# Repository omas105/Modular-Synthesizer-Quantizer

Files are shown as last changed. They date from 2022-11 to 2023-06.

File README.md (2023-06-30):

# Modular-Synthesizer-Quantizer
Modular Synthesizer Quantizer with Arduino nano and MCP4921 DAC

Inspired by [Hagiwo](https://note.com/solder_state/n/nde97a0516f03) and [luislutz's](https://github.com/luislutz/Arduino_Quantizer) design

<table>
  <tr>    
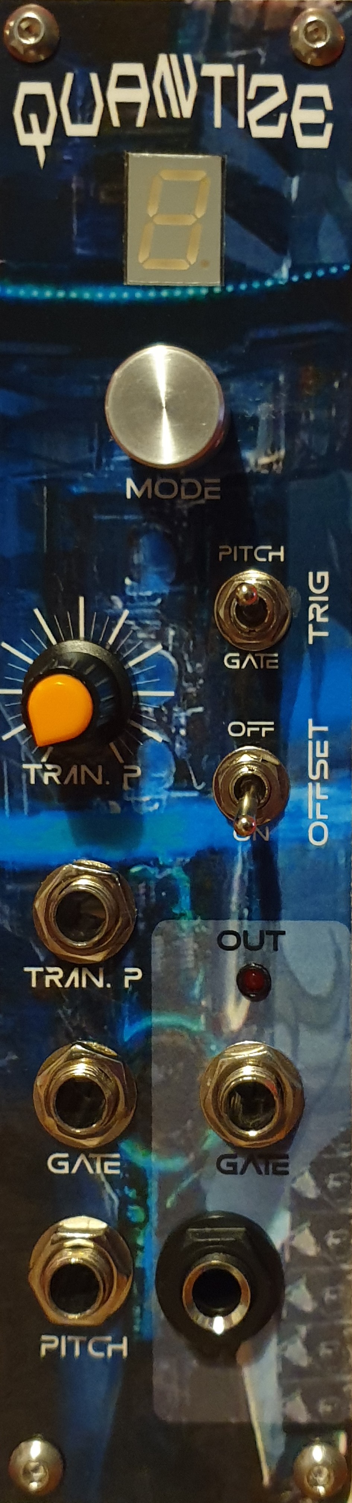
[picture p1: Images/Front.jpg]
    <td></td>
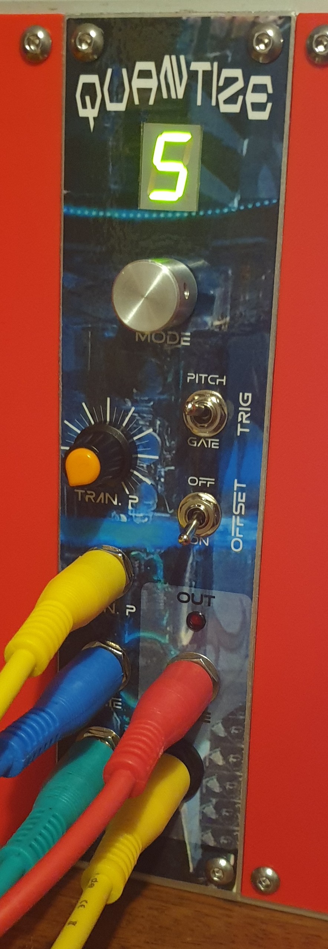
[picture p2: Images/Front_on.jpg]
    <td></td>
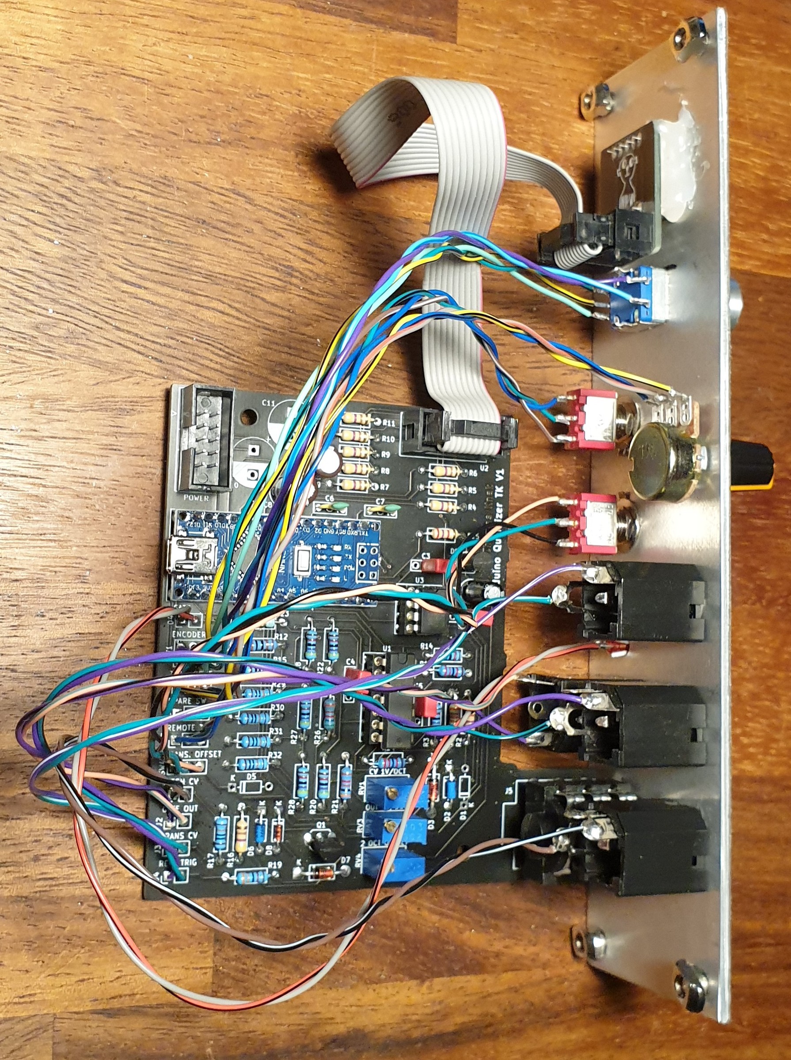
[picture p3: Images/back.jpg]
    <td></td>
  </tr>
 </table>

## Inputs
Pitch CV [0-7V] - Voltage to be quantized.

Trigger [2-12V] - Generate new quantized CV.

Transpose [0-5V] - Transpose quantized CV.

## Outputs
QV [0-9V] - Quantized CV.

Gate [0-10V] - Generates a pulse when QV i changed.

## Knops and switches
Transpose knop - Transpose QV 7 octaves.

Trigger switch - In OFF state QV is only changes when reciving a input trigger signal. In ON state QV is changes when pitch CV or transpose changes to a new note.

Offset switch - Transpose QV 2 octaves.

Mode selector - Encoder to change scales, transpose mode and root note.

<table>
  <tr>
   <td><b>Scale</b></td>
   <td><b>Root note</b></td>
   <td><b>Transpose mode</b></td>   
 </tr>
  <td>Turn mode knop</td>
  <td>Click and hold mode knop while turning</td>
  <td>Double click and turn mode knop</td>
 <tr>    
   <td>
    
| Number | Scale |
|---|---|
|0 |Major|
|1 |Major pentatonic|
|2 |Major pentatonic + 7|
|3 |Natural Minor|
|4 |Minor pentatonic|
|5 |Harmonic minor|
|6 |Melodic minor|
|7 |Blues|
|8 |Chromatic|
|9 |Octave|
   </td>

   <td>
    
| Display | Note |
|---|---|
| C | C |
| C. | C# |
| d | D |
| d. | D# |
| E | E |
| F | F |
| F. | F# |
| G | G |
| G. | G# |
| A | A |
| A. | A# |
| b | B |
   </td>

   <td>
     
| Display | Mode |
|-|-|
| Top | 12 Semitones
| Midt | 7 Semitones|
| Bottom | 1 Semitone| 
   </td>
  
  </tr>
 </table>

# PCB

<table>
  <tr>
    <td>Front</td>
    <td>Back</td>
  </tr>
  <tr>    
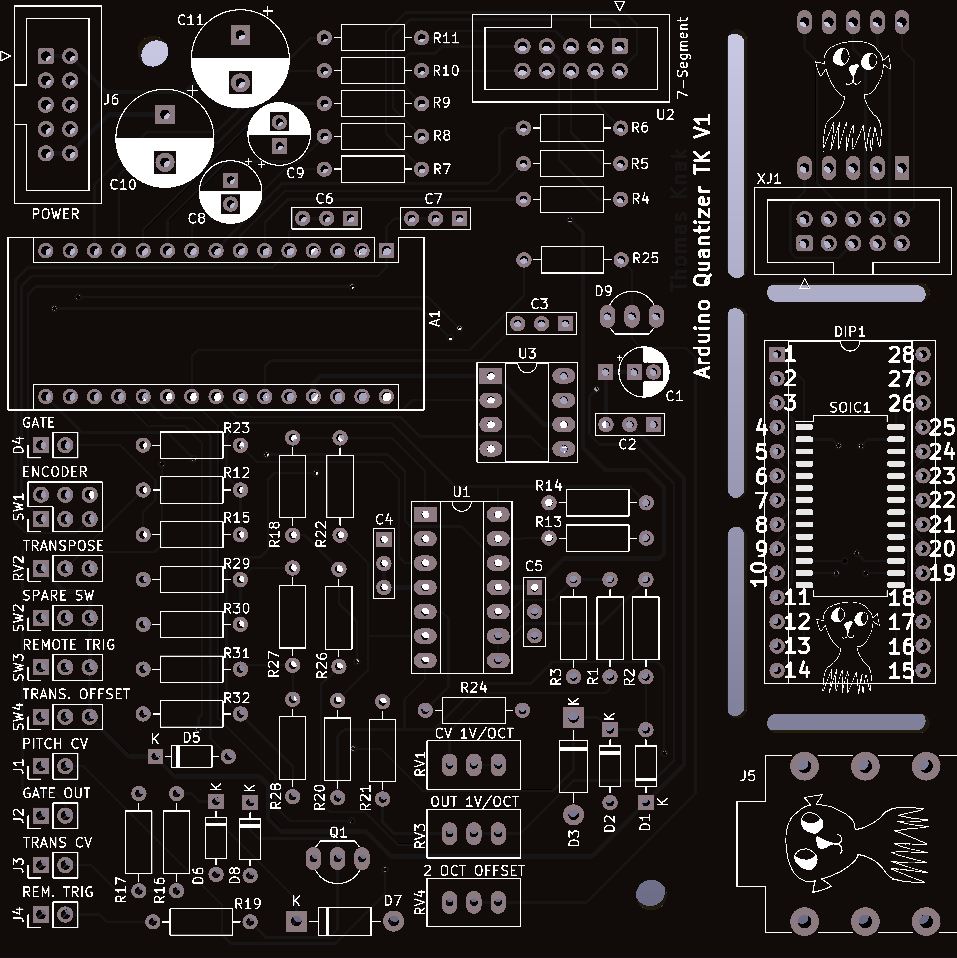
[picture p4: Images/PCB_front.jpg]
    <td></td>
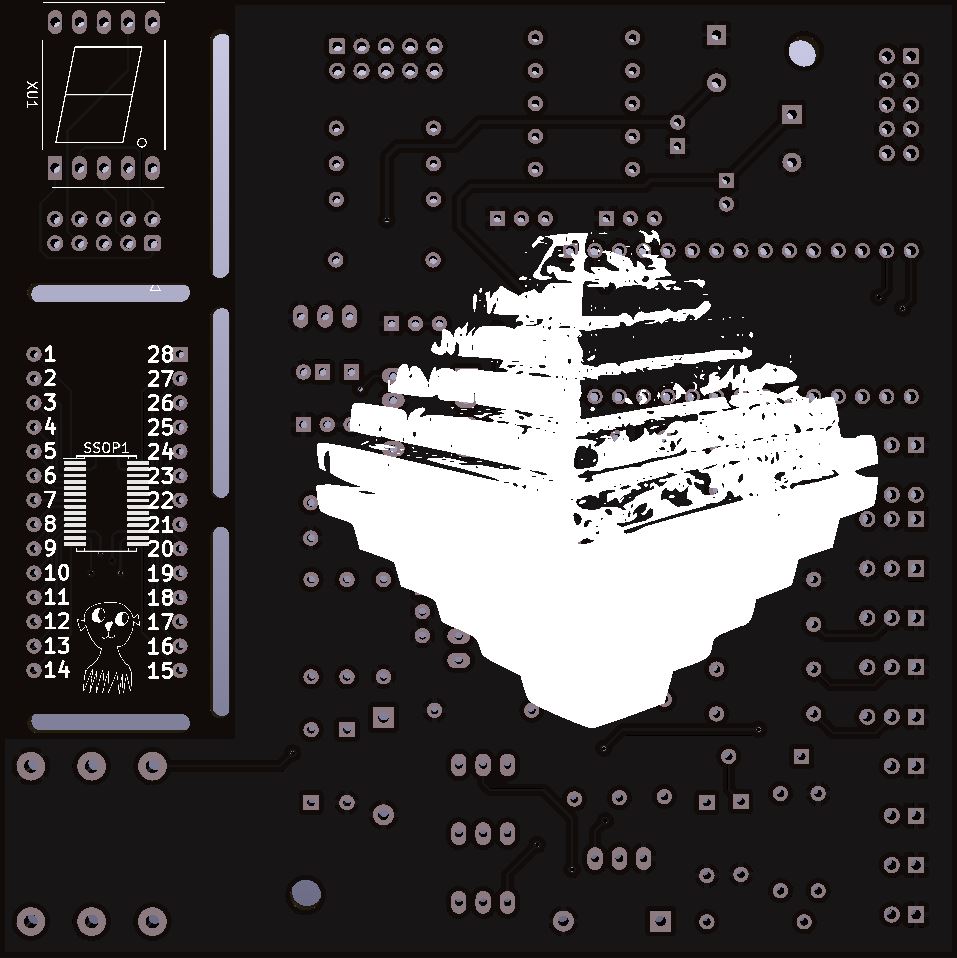
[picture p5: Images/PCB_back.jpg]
    <td></td>
  </tr>
 </table>

## License

[GNU General Public License (GPLv3)](LICENSE)

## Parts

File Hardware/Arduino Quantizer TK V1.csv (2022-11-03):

Source: | C:\Users\Thomas\Documents\Modular Synthesizer\TK Projektor\Arduino Quantizer TK\Hardware\Arduino Quantizer TK V1.sch
Date: | 03-11-2022 17:30:33
Tool: | Eeschema (5.1.10)-1
Generator: | C:\Program Files\KiCad\bin\scripting\plugins/bom_csv_grouped_by_value.py
Component Count: | 77
Individual Components:
Item | Qty | Reference(s) | Value | LibPart | Footprint | Datasheet | Text | text
 |  | A1 | Arduino_Nano_v3.x | MCU_Module:Arduino_Nano_v3.x | Module:Arduino_Nano | http://www.mouser.com/pdfdocs/Gravitech_Arduino_Nano3_0.pdf
 |  | C1 | 4µ7 | Device:CP | Thomas PCB:CP_Radial_D5.0mm_P2.00mm_P5.00mm | ~
 |  | C2 | 100n | Device:C | Thomas PCB:C_Rect_L7.0mm_W2.0mm_P2.50_P5.00mm | ~
 |  | C3 | 100n | Device:C | Thomas PCB:C_Rect_L7.0mm_W2.0mm_P2.50_P5.00mm | ~
 |  | C4 | 100n | Device:C | Thomas PCB:C_Rect_L7.0mm_W2.0mm_P2.50_P5.00mm | ~
 |  | C5 | 100n | Device:C | Thomas PCB:C_Rect_L7.0mm_W2.0mm_P2.50_P5.00mm | ~
 |  | C6 | 10n | Device:C | Thomas PCB:C_Rect_L7.0mm_W2.0mm_P2.50_P5.00mm | ~
 |  | C7 | 10n | Device:C | Thomas PCB:C_Rect_L7.0mm_W2.0mm_P2.50_P5.00mm | ~
 |  | C8 | 47µ | Device:CP | Capacitor_THT:CP_Radial_D6.3mm_P2.50mm | ~
 |  | C9 | 47µ | Device:CP | Capacitor_THT:CP_Radial_D6.3mm_P2.50mm | ~
 |  | C10 | 220µ | Device:CP | Thomas PCB:CP_Radial_D10.0mm_P5.00mm | ~
 |  | C11 | 220µ | Device:CP | Thomas PCB:CP_Radial_D10.0mm_P5.00mm | ~
 |  | D1 | BAT43 | Diode:BAT43 | Diode_THT:D_DO-35_SOD27_P7.62mm_Horizontal | http://www.vishay.com/docs/85660/bat42.pdf
 |  | D2 | BAT43 | Diode:BAT43 | Diode_THT:D_DO-35_SOD27_P7.62mm_Horizontal | http://www.vishay.com/docs/85660/bat42.pdf
 |  | D3 | 1N4733 5.1V | Diode:1N47xxA | Diode_THT:D_DO-41_SOD81_P10.16mm_Horizontal | https://www.vishay.com/docs/85816/1n4728a.pdf |  | 5.1V
 |  | D4 | Gate out LED | Device:LED_ALT | Connector_PinHeader_2.54mm:PinHeader_1x02_P2.54mm_Vertical | ~
 |  | D5 | BAT43 | Diode:BAT43 | Diode_THT:D_DO-35_SOD27_P7.62mm_Horizontal | http://www.vishay.com/docs/85660/bat42.pdf
 |  | D6 | BAT43 | Diode:BAT43 | Diode_THT:D_DO-35_SOD27_P7.62mm_Horizontal | http://www.vishay.com/docs/85660/bat42.pdf
 |  | D7 | 1N4733 5.1V | Diode:1N47xxA | Diode_THT:D_DO-41_SOD81_P10.16mm_Horizontal | https://www.vishay.com/docs/85816/1n4728a.pdf |  | 5.1V
 |  | D8 | 1N4148 | Diode:1N4148 | Diode_THT:D_DO-35_SOD27_P7.62mm_Horizontal | https://assets.nexperia.com/documents/data-sheet/1N4148_1N4448.pdf
 |  | D9 | LM336-2.5V | Thomas_Symbols:LM336-2.5V | Thomas PCB:TO-92_Inline_Wide_Longpads | ~
 |  | DIP1 | Conn_01x28 | Connector_Generic:Conn_01x28 | Package_DIP:DIP-28_W15.24mm_Socket | ~
 |  | J1 | Pitch CV | Connector:AudioJack2_SwitchT | Thomas PCB:Jack_PinHeader_1x02_P2.54mm_Vertical | ~ | 0-7V
 |  | J2 | Gate out | Connector:AudioJack2 | Thomas PCB:Jack_PinHeader_1x02_P2.54mm_Vertical | ~ |  | 0-10V
 |  | J3 | Transpose CV | Connector:AudioJack2_SwitchT | Thomas PCB:Jack_PinHeader_1x02_P2.54mm_Vertical | ~ | 0-5V
 |  | J4 | Remote trigger | Connector:AudioJack2 | Thomas PCB:Jack_PinHeader_1x02_P2.54mm_Vertical | ~ | 2-12V
 |  | J5 | QV out | Connector:AudioJack2 | Connector_Audio:Jack_6.35mm_Neutrik_NMJ6HFD2_Horizontal | ~
 |  | J6 | Power | Thomas_Symbols:Eurorack_power_Conn_01x10 | Connector_IDC:IDC-Header_2x05_P2.54mm_Vertical | ~
 |  | Q1 | BC547 | Transistor_BJT:BC547 | Thomas PCB:TO-92_Inline_Wide_Longpads | https://www.onsemi.com/pub/Collateral/BC550-D.pdf
 |  | R1 | 16K | Device:R | Resistor_THT:R_Axial_DIN0207_L6.3mm_D2.5mm_P10.16mm_Horizontal | ~
 |  | R2 | 470R | Device:R | Resistor_THT:R_Axial_DIN0207_L6.3mm_D2.5mm_P10.16mm_Horizontal | ~
 |  | R3 | 47K | Device:R | Resistor_THT:R_Axial_DIN0207_L6.3mm_D2.5mm_P10.16mm_Horizontal | ~
 |  | R4 | 300E | Device:R | Resistor_THT:R_Axial_DIN0207_L6.3mm_D2.5mm_P10.16mm_Horizontal | ~
 |  | R5 | 300E | Device:R | Resistor_THT:R_Axial_DIN0207_L6.3mm_D2.5mm_P10.16mm_Horizontal | ~
 |  | R6 | 300E | Device:R | Resistor_THT:R_Axial_DIN0207_L6.3mm_D2.5mm_P10.16mm_Horizontal | ~
 |  | R7 | 300E | Device:R | Resistor_THT:R_Axial_DIN0207_L6.3mm_D2.5mm_P10.16mm_Horizontal | ~
 |  | R8 | 300E | Device:R | Resistor_THT:R_Axial_DIN0207_L6.3mm_D2.5mm_P10.16mm_Horizontal | ~
 |  | R9 | 300E | Device:R | Resistor_THT:R_Axial_DIN0207_L6.3mm_D2.5mm_P10.16mm_Horizontal | ~
 |  | R10 | 300E | Device:R | Resistor_THT:R_Axial_DIN0207_L6.3mm_D2.5mm_P10.16mm_Horizontal | ~
 |  | R11 | 300E | Device:R | Resistor_THT:R_Axial_DIN0207_L6.3mm_D2.5mm_P10.16mm_Horizontal | ~
 |  | R12 | 1K | Device:R | Resistor_THT:R_Axial_DIN0207_L6.3mm_D2.5mm_P10.16mm_Horizontal | ~
 |  | R13 | 24K | Device:R | Resistor_THT:R_Axial_DIN0207_L6.3mm_D2.5mm_P10.16mm_Horizontal | ~
 |  | R14 | 47K | Device:R | Resistor_THT:R_Axial_DIN0207_L6.3mm_D2.5mm_P10.16mm_Horizontal | ~
 |  | R15 | 10K | Device:R | Resistor_THT:R_Axial_DIN0207_L6.3mm_D2.5mm_P10.16mm_Horizontal | ~
 |  | R16 | 470R | Device:R | Resistor_THT:R_Axial_DIN0207_L6.3mm_D2.5mm_P10.16mm_Horizontal | ~
 |  | R17 | 100K | Device:R | Resistor_THT:R_Axial_DIN0207_L6.3mm_D2.5mm_P10.16mm_Horizontal | ~
 |  | R18 | 47K | Device:R | Resistor_THT:R_Axial_DIN0207_L6.3mm_D2.5mm_P10.16mm_Horizontal | ~
 |  | R19 | 33K | Device:R | Resistor_THT:R_Axial_DIN0207_L6.3mm_D2.5mm_P10.16mm_Horizontal | ~
 |  | R20 | 47K | Device:R | Resistor_THT:R_Axial_DIN0207_L6.3mm_D2.5mm_P10.16mm_Horizontal | ~
 |  | R21 | 30K | Device:R | Resistor_THT:R_Axial_DIN0207_L6.3mm_D2.5mm_P10.16mm_Horizontal | ~
 |  | R22 | 47K | Device:R | Resistor_THT:R_Axial_DIN0207_L6.3mm_D2.5mm_P10.16mm_Horizontal | ~
 |  | R23 | 22K | Device:R | Resistor_THT:R_Axial_DIN0207_L6.3mm_D2.5mm_P10.16mm_Horizontal | ~
 |  | R24 | 22K | Device:R | Resistor_THT:R_Axial_DIN0207_L6.3mm_D2.5mm_P10.16mm_Horizontal | ~
 |  | R25 | 2K7 | Device:R | Resistor_THT:R_Axial_DIN0207_L6.3mm_D2.5mm_P10.16mm_Horizontal | ~
 |  | R26 | 56K | Device:R | Resistor_THT:R_Axial_DIN0207_L6.3mm_D2.5mm_P10.16mm_Horizontal | ~
 |  | R27 | 47K | Device:R | Resistor_THT:R_Axial_DIN0207_L6.3mm_D2.5mm_P10.16mm_Horizontal | ~
 |  | R28 | 47K | Device:R | Resistor_THT:R_Axial_DIN0207_L6.3mm_D2.5mm_P10.16mm_Horizontal | ~
 |  | R29 | 100K | Device:R | Resistor_THT:R_Axial_DIN0207_L6.3mm_D2.5mm_P10.16mm_Horizontal | ~
 |  | R30 | 100K | Device:R | Resistor_THT:R_Axial_DIN0207_L6.3mm_D2.5mm_P10.16mm_Horizontal | ~
 |  | R31 | 100K | Device:R | Resistor_THT:R_Axial_DIN0207_L6.3mm_D2.5mm_P10.16mm_Horizontal | ~
 |  | R32 | 100K | Device:R | Resistor_THT:R_Axial_DIN0207_L6.3mm_D2.5mm_P10.16mm_Horizontal | ~
 |  | RV1 | 5K | Device:R_POT | Thomas PCB:Potentiometer_Bourns_3296W_Vertical_longpads_2 | ~
 |  | RV2 | 100K | Device:R_POT | Connector_PinHeader_2.54mm:PinHeader_1x03_P2.54mm_Vertical | ~ | Transpose
 |  | RV3 | 10K | Device:R_POT | Thomas PCB:Potentiometer_Bourns_3296W_Vertical_longpads_2 | ~
 |  | RV4 | 5K | Device:R_POT | Thomas PCB:Potentiometer_Bourns_3296W_Vertical_longpads_2 | ~
 |  | SOIC1 | Conn_01x28 | Connector_Generic:Conn_01x28 | Package_SO:SOIC-28W_7.5x18.7mm_P1.27mm | ~
 |  | SSOP1 | Conn_01x28 | Connector_Generic:Conn_01x28 | Package_SO:TSSOP-28_6.1x9.7mm_P0.65mm | ~
 |  | SSOP2 | Conn_01x28 | Connector_Generic:Conn_01x28 | Package_SO:TSSOP-28_4.4x9.7mm_P0.65mm | ~
 |  | SW1 | Rotary_Encoder_Switch | Device:Rotary_Encoder_Switch | Thomas PCB:Encoder_with_Switch_PinHeader_2x03_P2.54mm_Vertical | ~
 |  | SW2 | Spare SW | Switch:SW_SPDT | Connector_PinHeader_2.54mm:PinHeader_1x03_P2.54mm_Vertical | ~
 |  | SW3 | Remote trig | Switch:SW_SPDT | Connector_PinHeader_2.54mm:PinHeader_1x03_P2.54mm_Vertical | ~
 |  | SW4 | Transpose Offset | Switch:SW_SPDT | Connector_PinHeader_2.54mm:PinHeader_1x03_P2.54mm_Vertical | ~
 |  | U1 | TL074 | Amplifier_Operational:TL074 | Package_DIP:DIP-14_W7.62mm_Socket_LongPads | http://www.ti.com/lit/ds/symlink/tl071.pdf
 |  | U2 | SC52-11GWA | Display_Character:KCSC02-123 | Thomas PCB:Eurorack_power_IDC-Header_2x05_P2.54mm_Vertical | http://www.kingbright.com/attachments/file/psearch/000/00/00/KCSC02-123(Ver.10A).pdf
 |  | U3 | MCP4921-EP | Analog_DAC:MCP4921-EP | Package_DIP:DIP-8_W7.62mm_Socket_LongPads | http://ww1.microchip.com/downloads/en/devicedoc/21897a.pdf
 |  | XJ1 | 7-Segment | Thomas_Symbols:Eurorack_power_Conn_01x10 | Connector_IDC:IDC-Header_2x05_P2.54mm_Vertical | ~
 |  | XU1 | SC52-11GWA | Display_Character:KCSC02-123 | Thomas PCB:7Segment_SC52-11GWA | http://www.kingbright.com/attachments/file/psearch/000/00/00/KCSC02-123(Ver.10A).pdf
Collated Components:
Item | Qty | Reference(s) | Value | LibPart | Footprint | Datasheet | Text | text
1 | 1 | A1 | Arduino_Nano_v3.x | MCU_Module:Arduino_Nano_v3.x | Module:Arduino_Nano | http://www.mouser.com/pdfdocs/Gravitech_Arduino_Nano3_0.pdf
2 | 1 | C1 | 4µ7 | Device:CP | Thomas PCB:CP_Radial_D5.0mm_P2.00mm_P5.00mm | ~
3 | 4 | C2, C3, C4, C5 | 100n | Device:C | Thomas PCB:C_Rect_L7.0mm_W2.0mm_P2.50_P5.00mm | ~
4 | 2 | C6, C7 | 10n | Device:C | Thomas PCB:C_Rect_L7.0mm_W2.0mm_P2.50_P5.00mm | ~
5 | 2 | C8, C9 | 47µ | Device:CP | Capacitor_THT:CP_Radial_D6.3mm_P2.50mm | ~
6 | 2 | C10, C11 | 220µ | Device:CP | Thomas PCB:CP_Radial_D10.0mm_P5.00mm | ~
7 | 4 | D1, D2, D5, D6 | BAT43 | Diode:BAT43 | Diode_THT:D_DO-35_SOD27_P7.62mm_Horizontal | http://www.vishay.com/docs/85660/bat42.pdf
8 | 2 | D3, D7 | 1N4733 5.1V | Diode:1N47xxA | Diode_THT:D_DO-41_SOD81_P10.16mm_Horizontal | https://www.vishay.com/docs/85816/1n4728a.pdf |  | 5.1V
9 | 1 | D4 | Gate out LED | Device:LED_ALT | Connector_PinHeader_2.54mm:PinHeader_1x02_P2.54mm_Vertical | ~
10 | 1 | D8 | 1N4148 | Diode:1N4148 | Diode_THT:D_DO-35_SOD27_P7.62mm_Horizontal | https://assets.nexperia.com/documents/data-sheet/1N4148_1N4448.pdf
11 | 1 | D9 | LM336-2.5V | Thomas_Symbols:LM336-2.5V | Thomas PCB:TO-92_Inline_Wide_Longpads | ~
12 | 1 | DIP1 | Conn_01x28 | Connector_Generic:Conn_01x28 | Package_DIP:DIP-28_W15.24mm_Socket | ~
13 | 1 | J1 | Pitch CV | Connector:AudioJack2_SwitchT | Thomas PCB:Jack_PinHeader_1x02_P2.54mm_Vertical | ~ | 0-7V
14 | 1 | J2 | Gate out | Connector:AudioJack2 | Thomas PCB:Jack_PinHeader_1x02_P2.54mm_Vertical | ~ |  | 0-10V
15 | 1 | J3 | Transpose CV | Connector:AudioJack2_SwitchT | Thomas PCB:Jack_PinHeader_1x02_P2.54mm_Vertical | ~ | 0-5V
16 | 1 | J4 | Remote trigger | Connector:AudioJack2 | Thomas PCB:Jack_PinHeader_1x02_P2.54mm_Vertical | ~ | 2-12V
17 | 1 | J5 | QV out | Connector:AudioJack2 | Connector_Audio:Jack_6.35mm_Neutrik_NMJ6HFD2_Horizontal | ~
18 | 1 | J6 | Power | Thomas_Symbols:Eurorack_power_Conn_01x10 | Connector_IDC:IDC-Header_2x05_P2.54mm_Vertical | ~
19 | 1 | Q1 | BC547 | Transistor_BJT:BC547 | Thomas PCB:TO-92_Inline_Wide_Longpads | https://www.onsemi.com/pub/Collateral/BC550-D.pdf
20 | 1 | R1 | 16K | Device:R | Resistor_THT:R_Axial_DIN0207_L6.3mm_D2.5mm_P10.16mm_Horizontal | ~
21 | 2 | R2, R16 | 470R | Device:R | Resistor_THT:R_Axial_DIN0207_L6.3mm_D2.5mm_P10.16mm_Horizontal | ~
22 | 7 | R3, R14, R18, R20, R22, R27, R28 | 47K | Device:R | Resistor_THT:R_Axial_DIN0207_L6.3mm_D2.5mm_P10.16mm_Horizontal | ~
23 | 8 | R4, R5, R6, R7, R8, R9, R10, R11 | 300E | Device:R | Resistor_THT:R_Axial_DIN0207_L6.3mm_D2.5mm_P10.16mm_Horizontal | ~
24 | 1 | R12 | 1K | Device:R | Resistor_THT:R_Axial_DIN0207_L6.3mm_D2.5mm_P10.16mm_Horizontal | ~
25 | 1 | R13 | 24K | Device:R | Resistor_THT:R_Axial_DIN0207_L6.3mm_D2.5mm_P10.16mm_Horizontal | ~
26 | 1 | R15 | 10K | Device:R | Resistor_THT:R_Axial_DIN0207_L6.3mm_D2.5mm_P10.16mm_Horizontal | ~
27 | 5 | R17, R29, R30, R31, R32 | 100K | Device:R | Resistor_THT:R_Axial_DIN0207_L6.3mm_D2.5mm_P10.16mm_Horizontal | ~
28 | 1 | R19 | 33K | Device:R | Resistor_THT:R_Axial_DIN0207_L6.3mm_D2.5mm_P10.16mm_Horizontal | ~
29 | 1 | R21 | 30K | Device:R | Resistor_THT:R_Axial_DIN0207_L6.3mm_D2.5mm_P10.16mm_Horizontal | ~
30 | 2 | R23, R24 | 22K | Device:R | Resistor_THT:R_Axial_DIN0207_L6.3mm_D2.5mm_P10.16mm_Horizontal | ~
31 | 1 | R25 | 2K7 | Device:R | Resistor_THT:R_Axial_DIN0207_L6.3mm_D2.5mm_P10.16mm_Horizontal | ~
32 | 1 | R26 | 56K | Device:R | Resistor_THT:R_Axial_DIN0207_L6.3mm_D2.5mm_P10.16mm_Horizontal | ~
33 | 2 | RV1, RV4 | 5K | Device:R_POT | Thomas PCB:Potentiometer_Bourns_3296W_Vertical_longpads_2 | ~
34 | 1 | RV2 | 100K | Device:R_POT | Connector_PinHeader_2.54mm:PinHeader_1x03_P2.54mm_Vertical | ~ | Transpose
35 | 1 | RV3 | 10K | Device:R_POT | Thomas PCB:Potentiometer_Bourns_3296W_Vertical_longpads_2 | ~
36 | 1 | SOIC1 | Conn_01x28 | Connector_Generic:Conn_01x28 | Package_SO:SOIC-28W_7.5x18.7mm_P1.27mm | ~
37 | 1 | SSOP1 | Conn_01x28 | Connector_Generic:Conn_01x28 | Package_SO:TSSOP-28_6.1x9.7mm_P0.65mm | ~
38 | 1 | SSOP2 | Conn_01x28 | Connector_Generic:Conn_01x28 | Package_SO:TSSOP-28_4.4x9.7mm_P0.65mm | ~
39 | 1 | SW1 | Rotary_Encoder_Switch | Device:Rotary_Encoder_Switch | Thomas PCB:Encoder_with_Switch_PinHeader_2x03_P2.54mm_Vertical | ~
40 | 1 | SW2 | Spare SW | Switch:SW_SPDT | Connector_PinHeader_2.54mm:PinHeader_1x03_P2.54mm_Vertical | ~
41 | 1 | SW3 | Remote trig | Switch:SW_SPDT | Connector_PinHeader_2.54mm:PinHeader_1x03_P2.54mm_Vertical | ~
42 | 1 | SW4 | Transpose Offset | Switch:SW_SPDT | Connector_PinHeader_2.54mm:PinHeader_1x03_P2.54mm_Vertical | ~
43 | 1 | U1 | TL074 | Amplifier_Operational:TL074 | Package_DIP:DIP-14_W7.62mm_Socket_LongPads | http://www.ti.com/lit/ds/symlink/tl071.pdf
44 | 1 | U2 | SC52-11GWA | Display_Character:KCSC02-123 | Thomas PCB:Eurorack_power_IDC-Header_2x05_P2.54mm_Vertical | http://www.kingbright.com/attachments/file/psearch/000/00/00/KCSC02-123(Ver.10A).pdf
45 | 1 | U3 | MCP4921-EP | Analog_DAC:MCP4921-EP | Package_DIP:DIP-8_W7.62mm_Socket_LongPads | http://ww1.microchip.com/downloads/en/devicedoc/21897a.pdf
46 | 1 | XJ1 | 7-Segment | Thomas_Symbols:Eurorack_power_Conn_01x10 | Connector_IDC:IDC-Header_2x05_P2.54mm_Vertical | ~
47 | 1 | XU1 | SC52-11GWA | Display_Character:KCSC02-123 | Thomas PCB:7Segment_SC52-11GWA | http://www.kingbright.com/attachments/file/psearch/000/00/00/KCSC02-123(Ver.10A).pdf

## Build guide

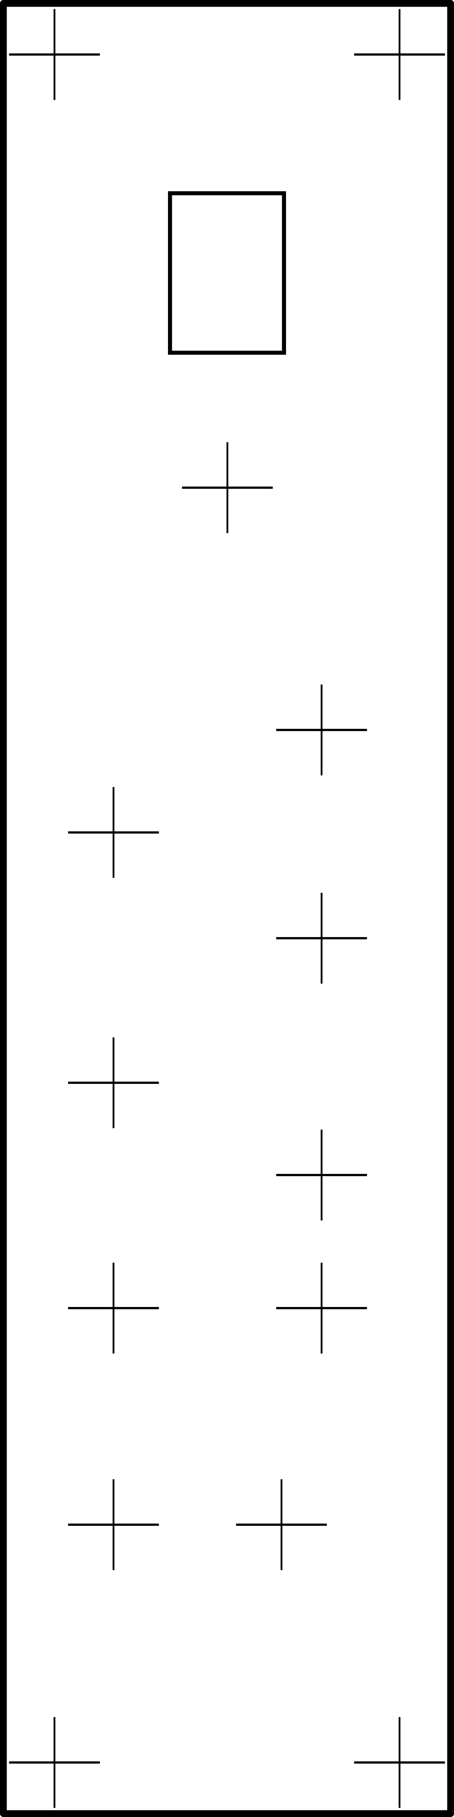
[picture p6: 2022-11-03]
Front panel/Arduino Quantizer TK front panel drill guide.png

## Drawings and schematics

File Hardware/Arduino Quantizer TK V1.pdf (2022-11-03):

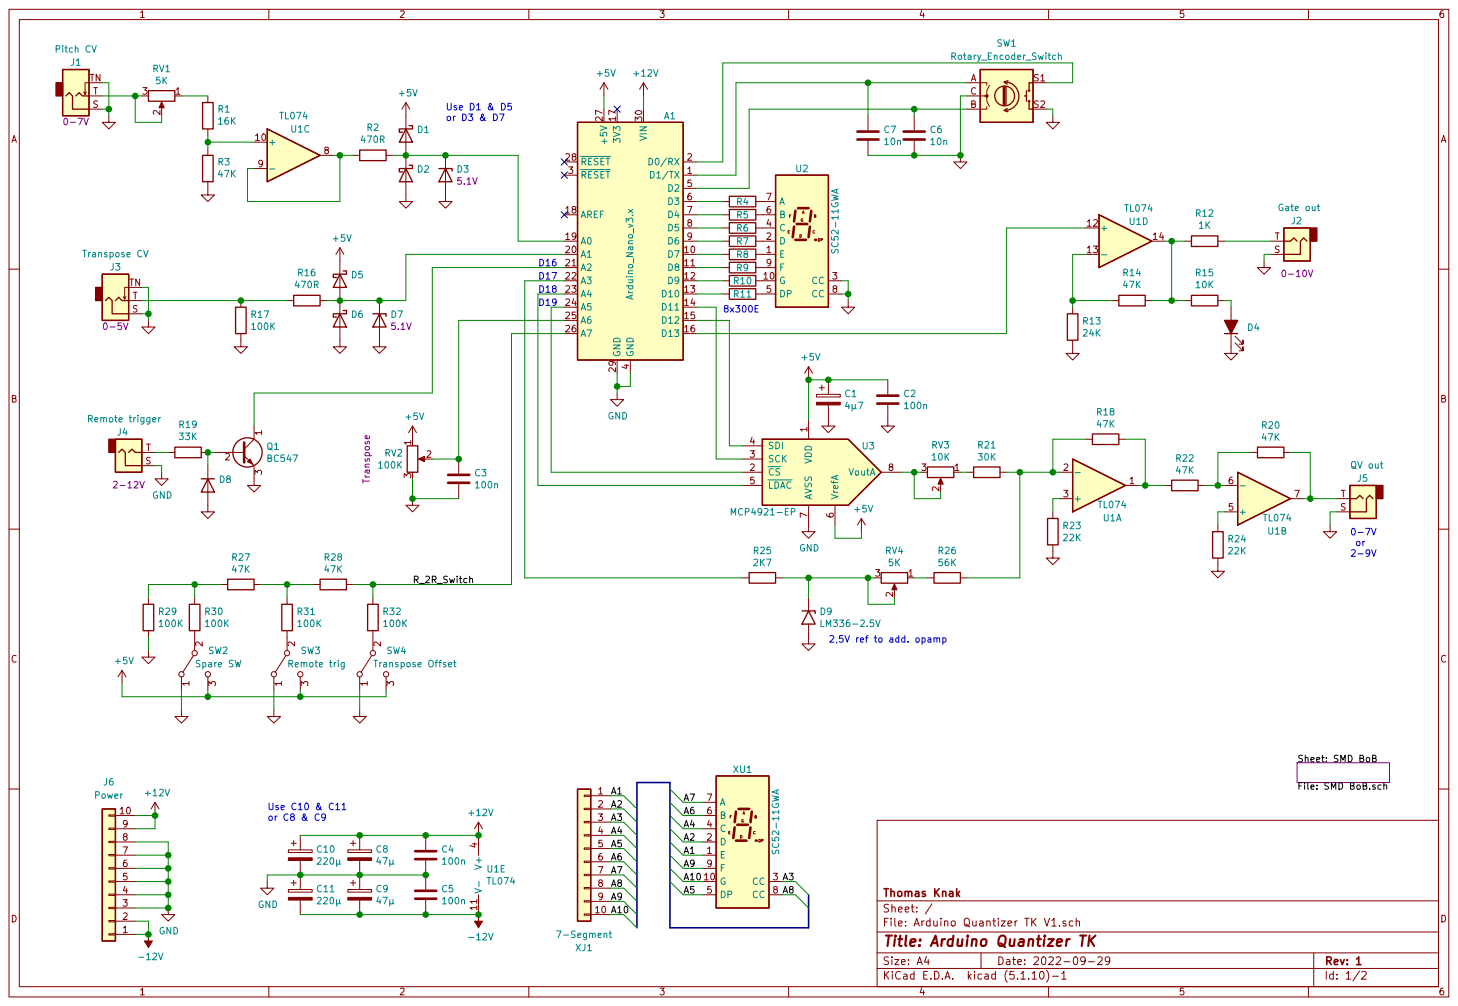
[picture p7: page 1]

2,5V ref to add. opamp

File: SMD BoB.sch

Id: 1/2 Title: Arduino Quantizer TK

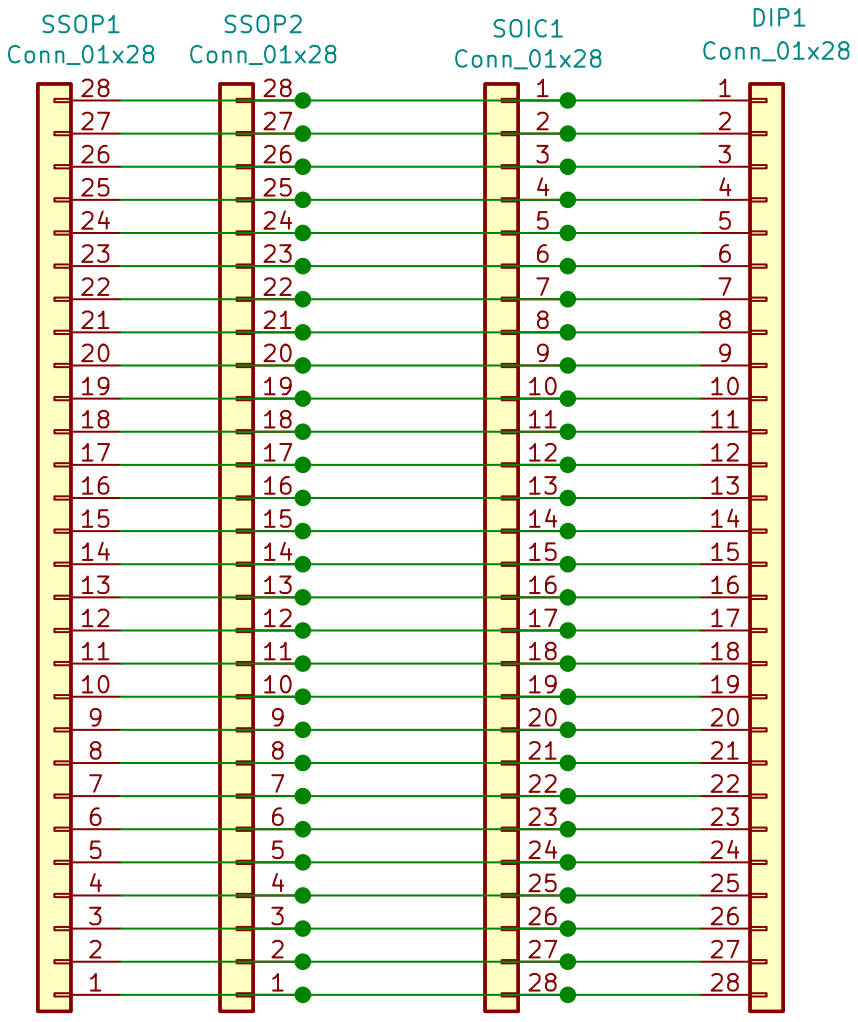
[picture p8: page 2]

20 | 20 | 283456789 SOIC1 Conn_01x28 1 283456789 DIP1 Conn_01x28 1
283456789 SSOP1 Conn_01x28 21 | 283456789 SSOP2 Conn_01x28 21 | 1 192 192

Id: 2/2 Title: File: SMD BoB.sch Sheet: /SMD BoB/ 1

27 | 27
26 | 26
25 | 25
24 | 24
23 | 23
22 | 22

192 13 | 192 13 | 16 16
18 | 18 | 11 11
17 | 17 | 12 12
16 | 16 | 13 13
15 | 15 | 14 14
14 | 14 | 15 15

12 | 12 | 17 17
11 | 11 | 18 18
10 | 10

20 20
21 21
22 22
23 23
24 24
25 25
26 26
27 27

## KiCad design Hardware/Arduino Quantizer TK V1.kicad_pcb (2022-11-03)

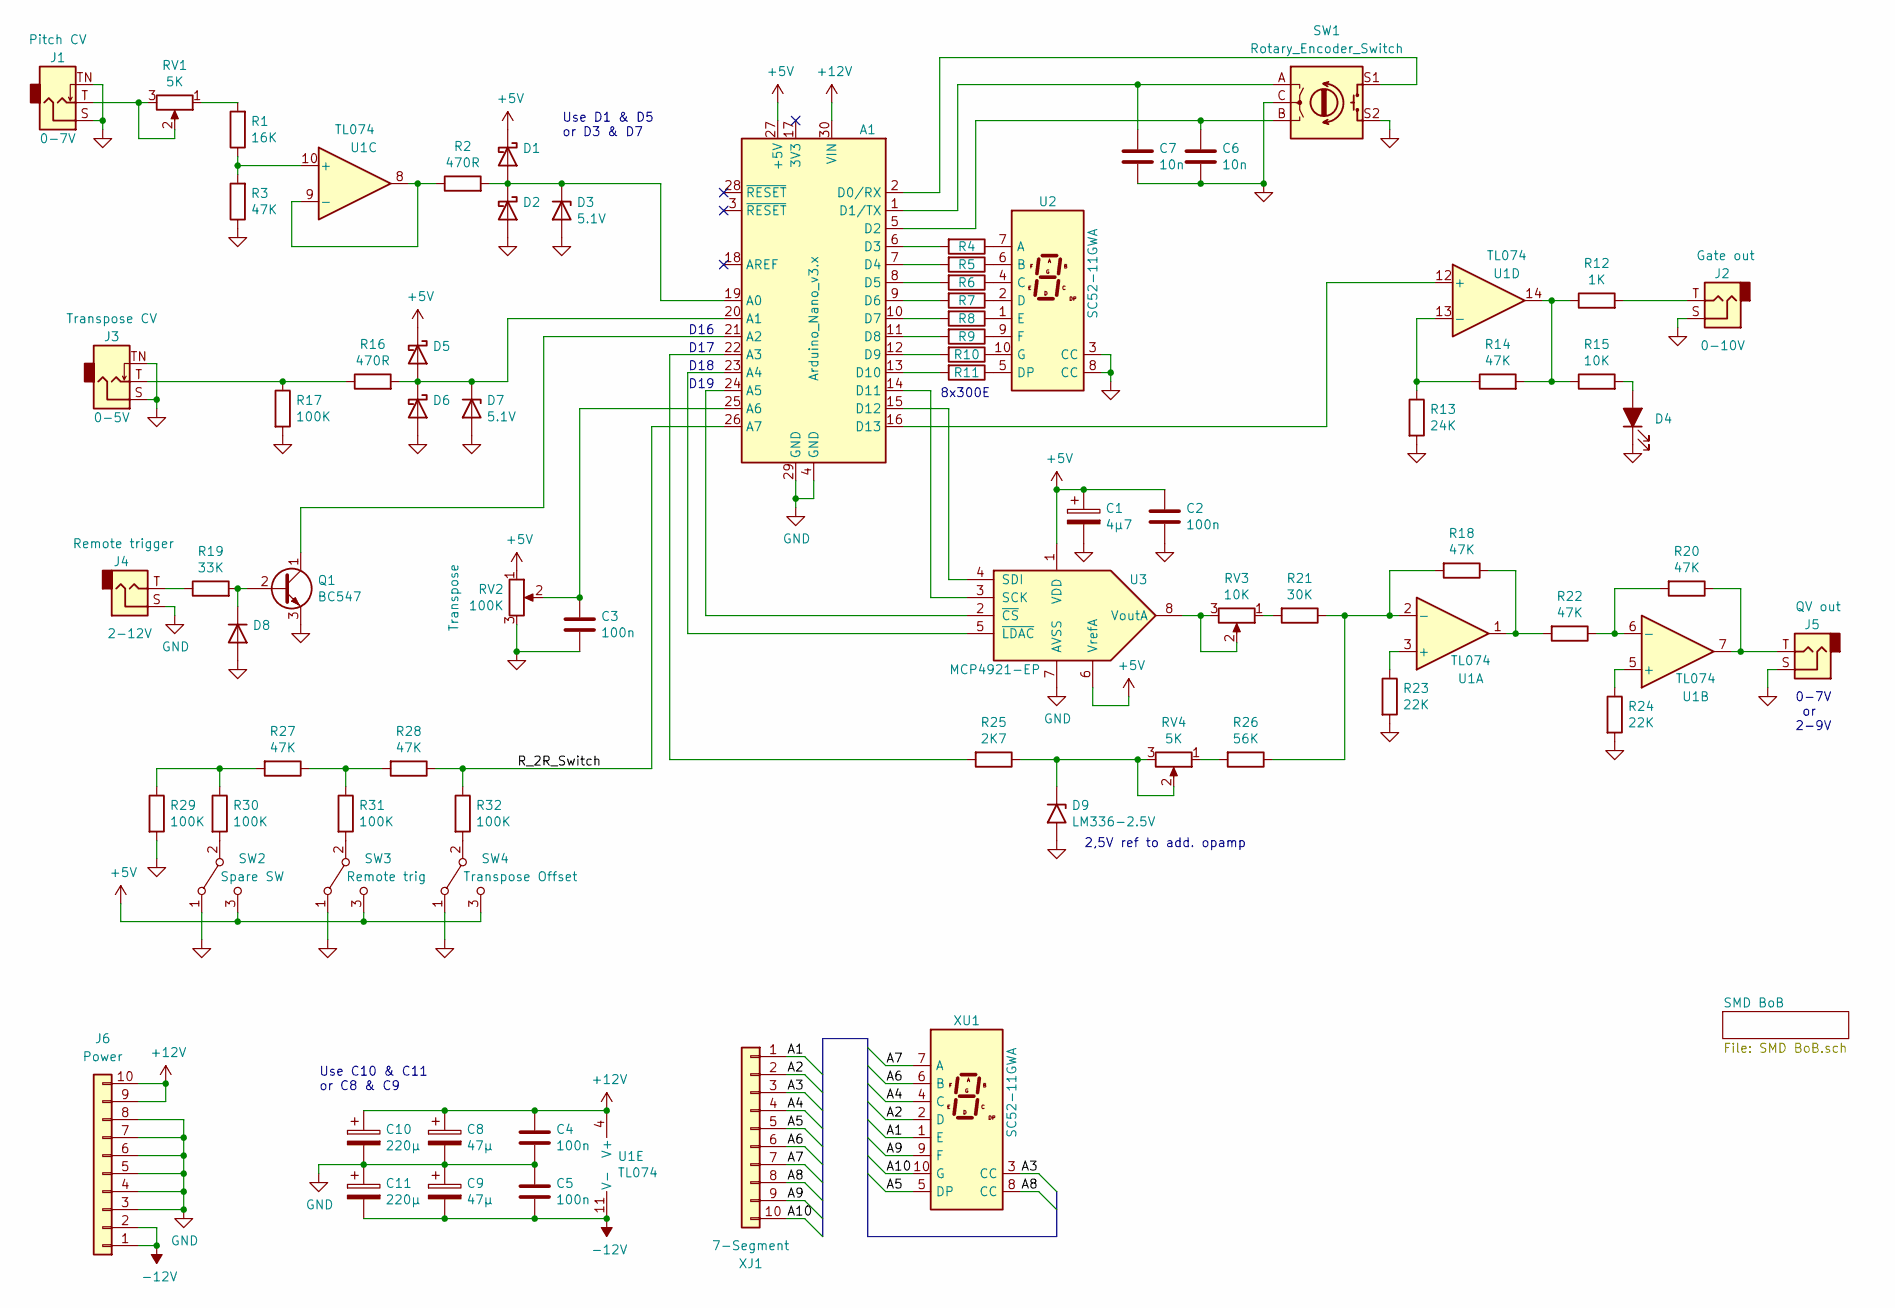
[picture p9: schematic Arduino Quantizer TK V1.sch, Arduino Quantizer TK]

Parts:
A1: Arduino_Nano_v3.x; Arduino_Nano
C1: 4µ7; CP_Radial_D5.0mm_P2.00mm_P5.00mm
C2, C3, C4, C5: 100n; C_Rect_L7.0mm_W2.0mm_P2.50_P5.00mm
C6, C7: 10n; C_Rect_L7.0mm_W2.0mm_P2.50_P5.00mm
C8, C9: 47µ; CP_Radial_D6.3mm_P2.50mm
C10, C11: 220µ; CP_Radial_D10.0mm_P5.00mm
D1, D2, D5, D6: BAT43; D_DO-35_SOD27_P7.62mm_Horizontal
D3, D7: 1N4733 5.1V; D_DO-41_SOD81_P10.16mm_Horizontal
D4: Gate out LED; PinHeader_1x02_P2.54mm_Vertical
D8: 1N4148; D_DO-35_SOD27_P7.62mm_Horizontal
D9: LM336-2.5V; TO-92_Inline_Wide_Longpads
J1: Pitch CV; Jack_PinHeader_1x02_P2.54mm_Vertical
J2: Gate out; Jack_PinHeader_1x02_P2.54mm_Vertical
J3: Transpose CV; Jack_PinHeader_1x02_P2.54mm_Vertical
J4: Remote trigger; Jack_PinHeader_1x02_P2.54mm_Vertical
J5: QV out; Jack_6.35mm_Neutrik_NMJ6HFD2_Horizontal
J6: Power; IDC-Header_2x05_P2.54mm_Vertical
Q1: BC547; TO-92_Inline_Wide_Longpads
R1: 16K; R_Axial_DIN0207_L6.3mm_D2.5mm_P10.16mm_Horizontal
R2, R16: 470R; R_Axial_DIN0207_L6.3mm_D2.5mm_P10.16mm_Horizontal
R3, R14, R18, R20, R22, R27, R28: 47K; R_Axial_DIN0207_L6.3mm_D2.5mm_P10.16mm_Horizontal
R4, R5, R6, R7, R8, R9, R10, R11: 300E; R_Axial_DIN0207_L6.3mm_D2.5mm_P10.16mm_Horizontal
R12: 1K; R_Axial_DIN0207_L6.3mm_D2.5mm_P10.16mm_Horizontal
R13: 24K; R_Axial_DIN0207_L6.3mm_D2.5mm_P10.16mm_Horizontal
R15: 10K; R_Axial_DIN0207_L6.3mm_D2.5mm_P10.16mm_Horizontal
R17, R29, R30, R31, R32: 100K; R_Axial_DIN0207_L6.3mm_D2.5mm_P10.16mm_Horizontal
R19: 33K; R_Axial_DIN0207_L6.3mm_D2.5mm_P10.16mm_Horizontal
R21: 30K; R_Axial_DIN0207_L6.3mm_D2.5mm_P10.16mm_Horizontal
R23, R24: 22K; R_Axial_DIN0207_L6.3mm_D2.5mm_P10.16mm_Horizontal
R25: 2K7; R_Axial_DIN0207_L6.3mm_D2.5mm_P10.16mm_Horizontal
R26: 56K; R_Axial_DIN0207_L6.3mm_D2.5mm_P10.16mm_Horizontal
RV1, RV4: 5K; Potentiometer_Bourns_3296W_Vertical_longpads_2
RV2: 100K; PinHeader_1x03_P2.54mm_Vertical
RV3: 10K; Potentiometer_Bourns_3296W_Vertical_longpads_2
SW1: Rotary_Encoder_Switch; Encoder_with_Switch_PinHeader_2x03_P2.54mm_Vertical
SW2: Spare SW; PinHeader_1x03_P2.54mm_Vertical
SW3: Remote trig; PinHeader_1x03_P2.54mm_Vertical
SW4: Transpose Offset; PinHeader_1x03_P2.54mm_Vertical
U1: TL074; DIP-14_W7.62mm_Socket_LongPads
U2: SC52-11GWA; Eurorack_power_IDC-Header_2x05_P2.54mm_Vertical
U3: MCP4921-EP; DIP-8_W7.62mm_Socket_LongPads
XJ1: 7-Segment; IDC-Header_2x05_P2.54mm_Vertical
XU1: SC52-11GWA; 7Segment_SC52-11GWA

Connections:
+5V: A1.27 (+5V), C1.1, C2.1, D1.1 (K), D5.1 (K), RV2.1, SW2.3 (C), SW3.3 (C), SW4.3 (C), U3.1 (VDD), U3.6 (VrefA)
+12V: A1.30 (VIN), C4.1, C8.1, C10.1, J6.9, J6.10, U1.4 (V+)
-12V: C5.2, C9.2, C11.2, J6.1, J6.2, U1.11 (V-)
/A1: XJ1.1, XU1.1 (E)
/A2: XJ1.2, XU1.2 (D)
/A3: XJ1.3, XU1.3 (CC)
/A4: XJ1.4, XU1.4 (C)
/A5: XJ1.5, XU1.5 (DP)
/A6: XJ1.6, XU1.6 (B)
/A7: XJ1.7, XU1.7 (A)
/A8: XJ1.8, XU1.8 (CC)
/A9: XJ1.9, XU1.9 (F)
/A10: XJ1.10, XU1.10 (G)
/R_2R_Switch: A1.26 (A7), R28.1, R32.1
GND: A1.4 (GND), A1.29 (GND), C1.2, C2.2, C3.2, C4.2, C5.1, C6.2, C7.2, C8.2, C9.1, C10.2, C11.1, D2.2 (A), D3.2 (A), D4.1 (K), D6.2 (A), D7.2 (A), D8.2 (A), D9.3 (A), J1.S, J1.TN, J2.S, J3.S, J3.TN, J4.S, J5.S, J6.3, J6.4, J6.5, J6.6, J6.7, J6.8, Q1.3 (E), R3.1, R13.2, R17.2, R23.2, R24.2, R29.2, RV2.3, SW1.C, SW1.S2, SW2.1 (A), SW3.1 (A), SW4.1 (A), U2.3 (CC), U2.8 (CC), U3.7 (AVSS)
unnamed: A1.1 (D1/TX), C7.1, SW1.A
unnamed: A1.2 (D0/RX), SW1.S1
unnamed: A1.5 (D2), C6.1, SW1.B
unnamed: A1.6 (D3), R4.2
unnamed: A1.7 (D4), R5.2
unnamed: A1.8 (D5), R6.2
unnamed: A1.9 (D6), R7.2
unnamed: A1.10 (D7), R8.2
unnamed: A1.11 (D8), R9.2
unnamed: A1.12 (D9), R10.2
unnamed: A1.13 (D10), R11.2
unnamed: A1.14 (D11), U3.3 (SCK)
unnamed: A1.15 (D12), U3.4 (SDI)
unnamed: A1.16 (D13), U1.12 (+)
unnamed: A1.19 (A0), D1.2 (A), D2.1 (K), D3.1 (K), R2.2
unnamed: A1.20 (A1), D5.2 (A), D6.1 (K), D7.1 (K), R16.2
unnamed: A1.21 (A2), Q1.1 (C)
unnamed: A1.22 (A3), R25.2
unnamed: A1.23 (A4), U3.5 (~LDAC~)
unnamed: A1.24 (A5), U3.2 (~CS~)
unnamed: A1.25 (A6), C3.1, RV2.2
unnamed: D4.2 (A), R15.2
unnamed: D8.1 (K), Q1.2 (B), R19.2
unnamed: D9.2 (K), R25.1, RV4.2, RV4.3
unnamed: J1.T, RV1.2, RV1.3
unnamed: J2.T, R12.2
unnamed: J3.T, R16.1, R17.1
unnamed: J4.T, R19.1
unnamed: J5.T, R20.1, U1.7
unnamed: R1.1, R3.2, U1.10 (+)
unnamed: R1.2, RV1.1
unnamed: R2.1, U1.8, U1.9 (-)
unnamed: R4.1, U2.7 (A)
unnamed: R5.1, U2.6 (B)
unnamed: R6.1, U2.4 (C)
unnamed: R7.1, U2.2 (D)
unnamed: R8.1, U2.1 (E)
unnamed: R9.1, U2.9 (F)
unnamed: R10.1, U2.10 (G)
unnamed: R11.1, U2.5 (DP)
unnamed: R12.1, R14.2, R15.1, U1.14
unnamed: R13.1, R14.1, U1.13 (-)
unnamed: R18.1, R22.2, U1.1
unnamed: R18.2, R21.1, R26.1, U1.2 (-)
unnamed: R20.2, R22.1, U1.6 (-)
unnamed: R21.2, RV3.1
unnamed: R23.1, U1.3 (+)
unnamed: R24.1, U1.5 (+)
unnamed: R26.2, RV4.1
unnamed: R27.1, R28.2, R31.1
unnamed: R27.2, R29.1, R30.1
unnamed: R30.2, SW2.2 (B)
unnamed: R31.2, SW3.2 (B)
unnamed: R32.2, SW4.2 (B)
unnamed: RV3.2, RV3.3, U3.8 (VoutA)

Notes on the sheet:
0-7V or 2-9V
2,5V ref to add. opamp
8x300E
D16
D17
D18
D19
Use C10 & C11 or C8 & C9
Use D1 & D5 or D3 & D7

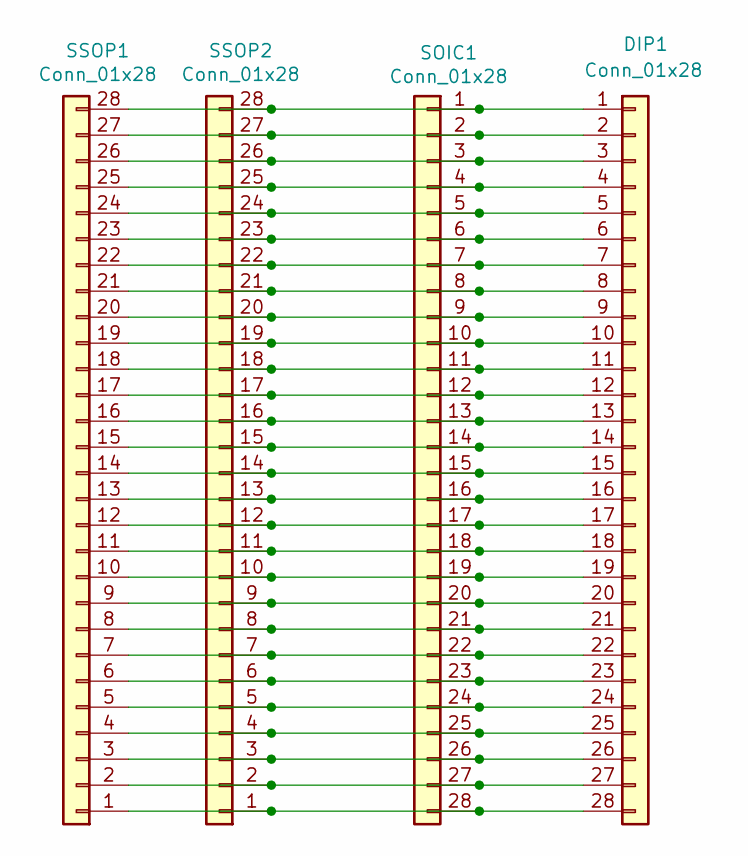
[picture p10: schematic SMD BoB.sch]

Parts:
DIP1: Conn_01x28; DIP-28_W15.24mm_Socket
SOIC1: Conn_01x28; SOIC-28W_7.5x18.7mm_P1.27mm
SSOP1: Conn_01x28; TSSOP-28_6.1x9.7mm_P0.65mm
SSOP2: Conn_01x28; TSSOP-28_4.4x9.7mm_P0.65mm

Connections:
unnamed: DIP1.1, SOIC1.1, SSOP1.28, SSOP2.28
unnamed: DIP1.2, SOIC1.2, SSOP1.27, SSOP2.27
unnamed: DIP1.3, SOIC1.3, SSOP1.26, SSOP2.26
unnamed: DIP1.4, SOIC1.4, SSOP1.25, SSOP2.25
unnamed: DIP1.5, SOIC1.5, SSOP1.24, SSOP2.24
unnamed: DIP1.6, SOIC1.6, SSOP1.23, SSOP2.23
unnamed: DIP1.7, SOIC1.7, SSOP1.22, SSOP2.22
unnamed: DIP1.8, SOIC1.8, SSOP1.21, SSOP2.21
unnamed: DIP1.9, SOIC1.9, SSOP1.20, SSOP2.20
unnamed: DIP1.10, SOIC1.10, SSOP1.19, SSOP2.19
unnamed: DIP1.11, SOIC1.11, SSOP1.18, SSOP2.18
unnamed: DIP1.12, SOIC1.12, SSOP1.17, SSOP2.17
unnamed: DIP1.13, SOIC1.13, SSOP1.16, SSOP2.16
unnamed: DIP1.14, SOIC1.14, SSOP1.15, SSOP2.15
unnamed: DIP1.15, SOIC1.15, SSOP1.14, SSOP2.14
unnamed: DIP1.16, SOIC1.16, SSOP1.13, SSOP2.13
unnamed: DIP1.17, SOIC1.17, SSOP1.12, SSOP2.12
unnamed: DIP1.18, SOIC1.18, SSOP1.11, SSOP2.11
unnamed: DIP1.19, SOIC1.19, SSOP1.10, SSOP2.10
unnamed: DIP1.20, SOIC1.20, SSOP1.9, SSOP2.9
unnamed: DIP1.21, SOIC1.21, SSOP1.8, SSOP2.8
unnamed: DIP1.22, SOIC1.22, SSOP1.7, SSOP2.7
unnamed: DIP1.23, SOIC1.23, SSOP1.6, SSOP2.6
unnamed: DIP1.24, SOIC1.24, SSOP1.5, SSOP2.5
unnamed: DIP1.25, SOIC1.25, SSOP1.4, SSOP2.4
unnamed: DIP1.26, SOIC1.26, SSOP1.3, SSOP2.3
unnamed: DIP1.27, SOIC1.27, SSOP1.2, SSOP2.2
unnamed: DIP1.28, SOIC1.28, SSOP1.1, SSOP2.1

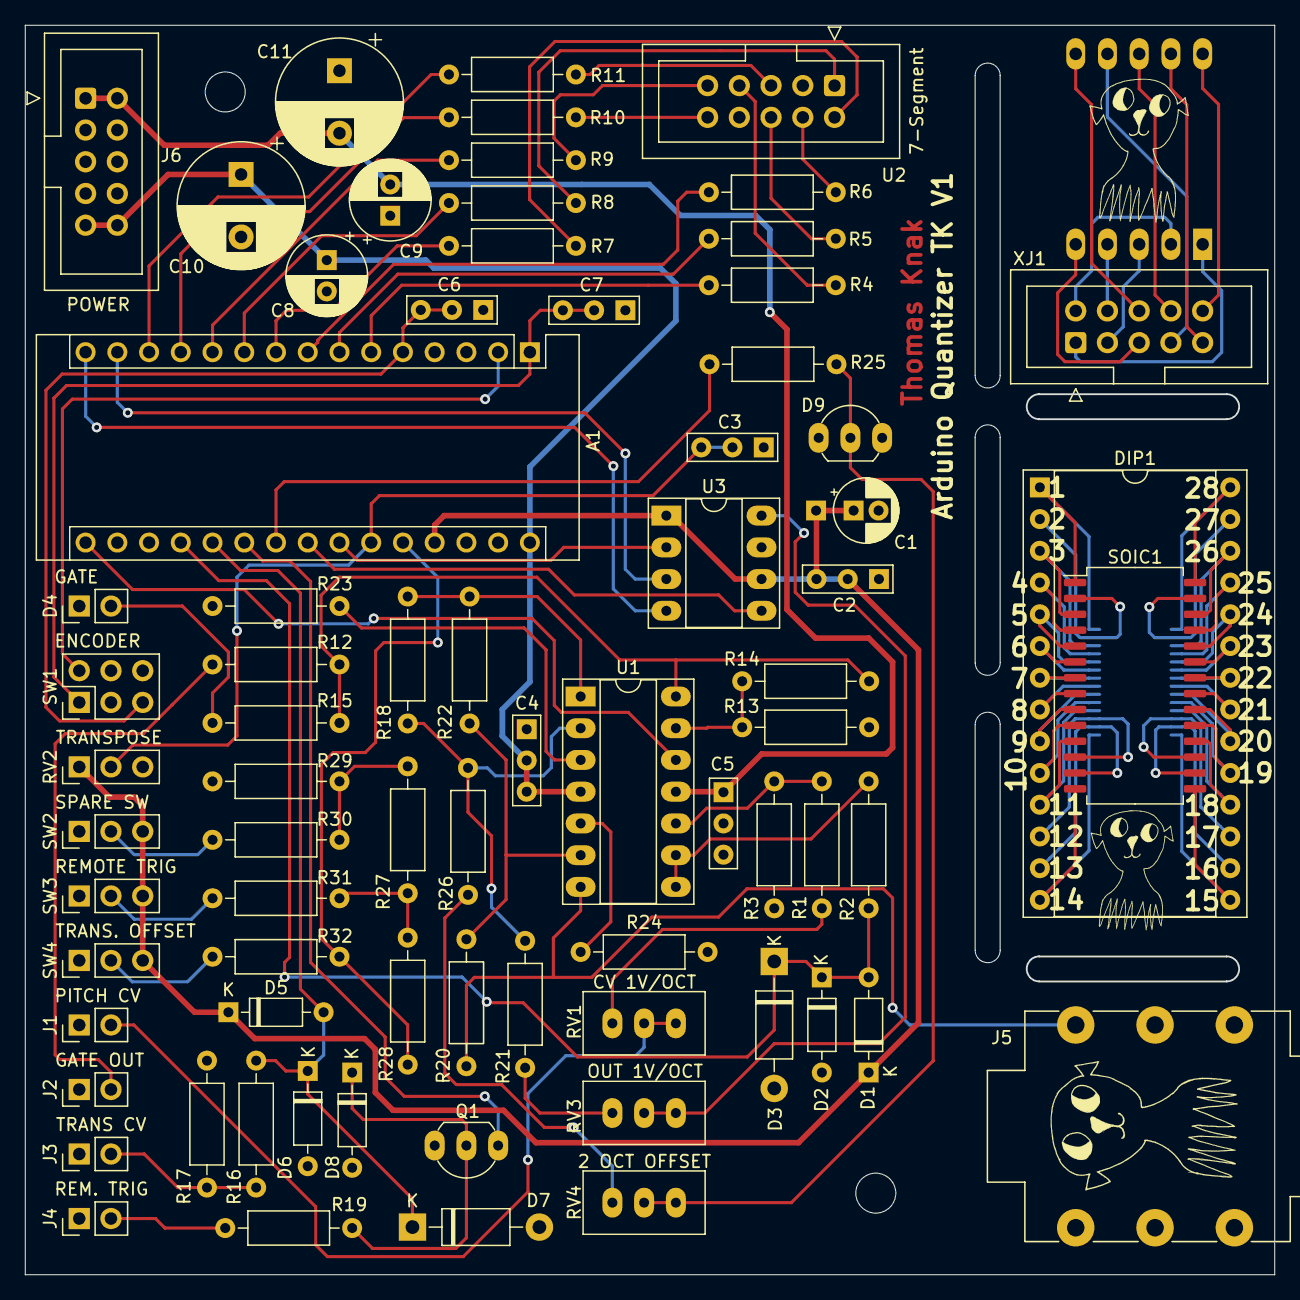
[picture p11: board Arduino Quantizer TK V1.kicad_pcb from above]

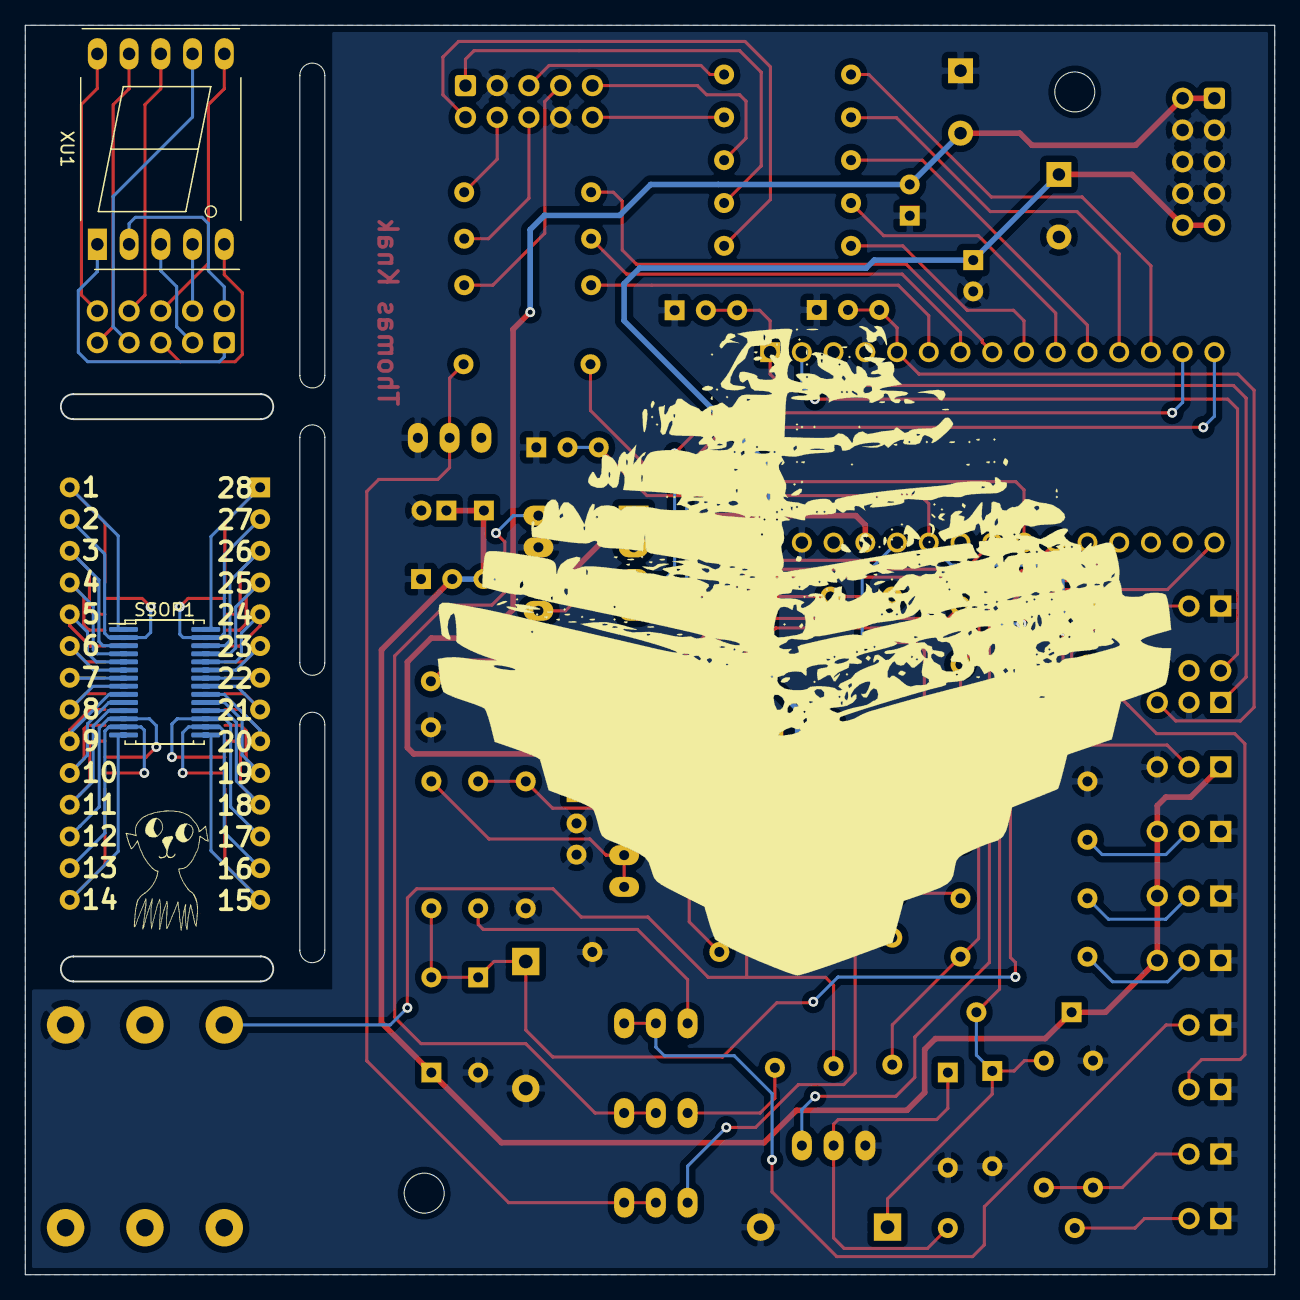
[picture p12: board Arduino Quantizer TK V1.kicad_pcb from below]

Board: 2 copper layers, 100.0 x 100.0 mm, 77 parts (3 on the bottom side), 98 nets.

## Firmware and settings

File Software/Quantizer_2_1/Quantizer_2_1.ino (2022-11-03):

/****************************************************************************************************************************
* Quantizer
* Designed for arduino nano
*
* -> 10 Scales
* -> 0-9 Volt output
* -> 3 Transpose modes
* -> Remote trigger
*
* By Thomas Knak
****************************************************************************************************************************/

#define  ENCODER_OPTIMIZE_INTERRUPTS
#include <Encoder.h>

#define ANALOG_PITCH_CV_PIN 0
#define ANALOG_TRANSPOSE_CV_PIN 1				// transpose CV input

#define ANALOG_TRANSPOSE_POT_PIN 6			// transpose potentiometer
#define ANALOG_SWITCH_IN_PIN 7			// R2R switch input
#define JITTER 5
#define TO_VOLT 293

#define ENCODER_A_PIN 1
#define ENCODER_B_PIN 2 // interrupt pin
#define ENCODER_SWITCH_PIN 0
Encoder encoder1(ENCODER_B_PIN, ENCODER_A_PIN);

#define DAC_SCK_PIN	11
#define DAC_SDI_PIN	12
#define DAC_LDAC_PIN 18
#define DAC_CS_PIN 19

#define REMOTE_TRIGGER_PIN 16			// Trigger input
#define GATE_PIN 13						// gate output
#define TRANSPOSE_OFFSET_PIN 17			// + 2 octave transpose output

// R2R analog switch bit position
#define SWITCH_TRANSPOSE_BIT 4
#define SWITCH_REMOTE_TRIGGER_BIT 2
#define SWITCH_SPARE_BIT 1

// Used with "old" valuse to force new analog reading
#define INVALID_VALUE 10000

// Number of loops gate is high. loop time ~500µS
#define GATE_TIME 80	// 40mS

// 7-segment output pins
#define SEG_A_PIN 3
#define SEG_B_PIN 4
#define SEG_C_PIN 5
#define SEG_D_PIN 6
#define SEG_E_PIN 7
#define SEG_F_PIN 8
#define SEG_G_PIN 9
#define SEG_DP_PIN 10

// 7-segment chars. Segment order as bite DP g f e d c b a, 0b00000110 turns on segment b and c thus showing nr 1
#define _0  0b00111111
#define _1  0b00000110
#define _2  0b01011011
#define _3  0b01001111
#define _4  0b01100110
#define _5  0b01101101
#define _6  0b01111101
#define _7  0b00000111
#define _8  0b01111111
#define _9  0b01101111
#define _DP 0b10000000

#define _C	0b00111001
#define _CS	0b10111001
#define _D	0b01011110
#define _DS 0b11011110
#define _E	0b01111001
#define _F	0b01110001
#define _FS	0b11110001
#define _G	0b00111101
#define _GS	0b10111101
#define _A	0b01110111
#define _AS	0b11110111
#define _B	0b01111100

// mode selector display
//#define _MODE_COUNT_WITH_OFFSET 10
#define _MODE_COUNT 3
#define _MODE_1 0b00001000
#define _MODE_2 0b01000000
#define _MODE_3 0b00000001

// 7-segment display presets
const static byte mode[] = { _MODE_1, _MODE_2, _MODE_3 };
const static byte nr[] = { _0, _1, _2, _3, _4, _5, _6, _7, _8, _9, _DP };
const static byte key[] = { _C, _CS, _D, _DS, _E, _F, _FS, _G, _GS, _A, _AS, _B };
const static int segment_array[] = { SEG_A_PIN, SEG_B_PIN, SEG_C_PIN, SEG_D_PIN, SEG_E_PIN, SEG_F_PIN, SEG_G_PIN, SEG_DP_PIN };

// MCP4921...
// (pin allocations for convenience in hardware hook-up)
#define pulseHigh(pin) {digitalWrite(pin, HIGH); digitalWrite(pin, LOW); }

byte upper_byte = 0x10;
byte lower_byte = 0;

// Chromatic (Analog in) 5V in - 7V out
//const static int ain_chromatic_scale[] = {
//	0, 6, 18, 30, 43, 55, 67, 79, 91, 104, 116, 128,
//	140, 152, 164, 177, 189, 201, 213, 225, 237, 250, 262, 274,
//	286, 298, 311, 323, 335, 347, 359, 371, 384, 396, 408, 420,
//	432, 445, 457, 469, 481, 493, 505, 518, 530, 542, 554, 566,
//	578, 591, 603, 615, 627, 639, 652, 664, 676, 688, 700, 712,
//	725, 737, 749, 761, 773, 786, 798, 810, 822, 834, 846, 859,
//	871, 883, 895, 907, 919, 932, 944, 956, 968, 980, 993, 1005,
//	1017
//};

// Chromatic scale (DAC) 7V
const static int dac_chromatic_scale[] = {
	0,49,98,146,195,244,293,341,390,439,488,536,
	585,634,683,731,780,829,878,926,975,1024,1073,1121,
	1170,1219,1268,1316,1365,1414,1463,1511,1560,1609,1658,1706,
	1755,1804,1853,1901,1950,1999,2048,2096,2145,2194,2243,2291,
	2340,2389,2438,2486,2535,2584,2633,2681,2730,2779,2828,2876,
	2925,2974,3023,3071,3120,3169,3218,3266,3315,3364,3413,3461,
	3510,3559,3608,3656,3705,3754,3803,3851,3900,3949,3998,4046,
	4095
};

// chromatic (DAC) 5V
//const static int dac_chromatic_scale[] = {
//	 0,  68, 137,  205,  273,  341,  410,  478,  546,  614,  683,  751,  
//	 819,  887,  956,  1024, 1092, 1161, 1229, 1297, 1365, 1434, 1502, 1570, 
//	 1638, 1707, 1775, 1843, 1911, 1980, 2048, 2116, 2185, 2253, 2321, 2389, 
//	 2458, 2526, 2594, 2662, 2731, 2799, 2867, 2935, 3004, 3072, 3140, 3209, 
//	 3277, 3345, 3413, 3482, 3550, 3618, 3686, 3755, 3823, 3891, 3959, 4028, 4095
//};

// Scales from chromatic
#define NR_OF_SCALES 10
#define NR_OF_KEYS 12
const static bool scale_array[10][12] = {
	{ true, false, true, false, true, true, false, true, false, true, false, true },        // Major
	{ true, false, true, false, true, false, false, true, false, true, false, false },      // Major pentatonic
	{ true, false, true, false, true, false, false, true, false, true, false, true },       // Major pentatonic + 7
	{ true, false, true, true, false, true, false, true, true, false, true, false },        // Natural Minor
	{ true, false, false, true, false, true, false, true, false, false, true, false },      // Minor pentatonic
	{ true, false, true, true, false, true, false, true, true, false, false, true },        // Harmonic minor
	{ true, false, true, true, false, true, false, true, false, true, false, true },        // Melodic minor
	{ true, false, false, true, false, true, true, true, false, false, true, false },       // Blues
	{ true, true, true, true, true, true, true, true, true, true, true, true},              // Chromatic
	{ true, false, false, false, false, false, false, false, false, false, false, false },  // Octave
};

static int DOUBLE_CLICK_TIME = 500;  //Max time beetween double click detection in ms

// 0 indexed (length -1)
int chromatic_scale_length = 0;
static int encoder1_counter = 0;
static int encoder1_move = 0;
static int encoder1_new_position = 0;

void setup() {
	//Serial.begin(9600);
	pinMode(GATE_PIN, OUTPUT);

	// 7-segment setup
	pinMode(SEG_A_PIN, OUTPUT);
	pinMode(SEG_B_PIN, OUTPUT);
	pinMode(SEG_C_PIN, OUTPUT);
	pinMode(SEG_D_PIN, OUTPUT);
	pinMode(SEG_E_PIN, OUTPUT);
	pinMode(SEG_F_PIN, OUTPUT);
	pinMode(SEG_G_PIN, OUTPUT);
	pinMode(SEG_DP_PIN, OUTPUT);

	// encoder setup
	pinMode(ENCODER_A_PIN, INPUT_PULLUP);
	pinMode(ENCODER_B_PIN, INPUT_PULLUP);
	pinMode(ENCODER_SWITCH_PIN, INPUT_PULLUP);

	pinMode(TRANSPOSE_OFFSET_PIN, OUTPUT); // 2V offset
	pinMode(REMOTE_TRIGGER_PIN, INPUT_PULLUP);

	DACsetup();
	chromatic_scale_length = (sizeof(dac_chromatic_scale) / sizeof(dac_chromatic_scale[0]) - 1);
}

void loop() {
	//***************************************************************************************************************************
	//:::::::::::::::::::::::::::::::::::::::::::::::::::::: Read encoder :::::::::::::::::::::::::::::::::::::::::::::::::::::::
	//***************************************************************************************************************************
	static int scale = 0;
	static int root_key = 0;
	static int transpose_mode = 0;
	static bool encoder1_double_click = false;
	static bool encoder1_first_click = false;
	static unsigned long encoder1_click_timer = 0;

	if (!digitalRead(ENCODER_SWITCH_PIN)) // switch on
	{
		// check if double click or not
		if (encoder1_first_click)
		{
			encoder1_first_click = false;
			if ((encoder1_click_timer + DOUBLE_CLICK_TIME) > millis())
			{
				encoder1_double_click = true;
				Segment_Display(mode[transpose_mode]);
			}
			else
			{
				Segment_Display(key[root_key]);
			}
			encoder1_click_timer = millis();
		}
		if (Encoder1_Move())
		{
			// double click mode selector 
			if (encoder1_double_click)
			{
				transpose_mode = (transpose_mode + encoder1_move + _MODE_COUNT) % _MODE_COUNT; //_MODE_COUNT_WITH_OFFSET) % _MODE_COUNT_WITH_OFFSET;
				Segment_Display(mode[transpose_mode]);
			}
			else // click key selector
			{
				root_key = (root_key + encoder1_move + NR_OF_KEYS) % NR_OF_KEYS; // count from 0 -> 11
				Segment_Display(key[root_key]);
			}
		}
	}
	else // switch off, scale selector
	{
		if (Encoder1_Move() || encoder1_first_click == false)
		{
			scale = (scale + encoder1_move + NR_OF_SCALES) % NR_OF_SCALES; // count from 0 -> 9
			Segment_Display(nr[scale]);
		}
		encoder1_first_click = true;
		encoder1_double_click = false;
	}

	//***************************************************************************************************************************
	//::::::::::::::::::::::::::::::::::::::::::::::::::::::: R2R switch ::::::::::::::::::::::::::::::::::::::::::::::::::::::::
	//***************************************************************************************************************************
	static int transpose_pot_old = INVALID_VALUE;
	static int switch_read_old = INVALID_VALUE;
	static int debounceR2R = 0;
	static int previous_note = INVALID_VALUE;
	static bool switch_remote_trigger = false;
	// 0 = transpose offset off, 1 = transpose offset on
	static bool switch_transpose_offset = false;
	static bool switch_transpose_offset_old = false;
	// enable transpose offset
	static bool transpose_offset = false;

	int switch_read = analogRead(ANALOG_SWITCH_IN_PIN);
	switch_read = map(switch_read, -64, 960, 0, 8);

	if (debounceR2R != 0)
	{
		if (debounceR2R == 1)  // debounce delay end
		{
			switch_read_old = switch_read;
			switch_remote_trigger = !(SWITCH_REMOTE_TRIGGER_BIT & switch_read); // remote trigger active low to avoide hazard state when switching transpose offset
			switch_transpose_offset = SWITCH_TRANSPOSE_BIT & switch_read;
			// if offset switch changed set new state
			if (switch_transpose_offset != switch_transpose_offset_old)
			{
				switch_transpose_offset_old = switch_transpose_offset;
				transpose_pot_old = INVALID_VALUE; // recalculate transpose when transpose offset changes
				previous_note = INVALID_VALUE;
				transpose_offset = switch_transpose_offset;
			}
		}
		debounceR2R--;
	}
	if (switch_read != switch_read_old && debounceR2R == 0)
	{
		debounceR2R = 3;		// start debounce delay
	}

	//****************************************************************************************************************************
	//::::::::::::::::::::::::::::::::::::::::::::::::::::::: Transpose pot ::::::::::::::::::::::::::::::::::::::::::::::::::::::
	//****************************************************************************************************************************
	static int transpose_pot = 0;
	int transpose_read = analogRead(ANALOG_TRANSPOSE_POT_PIN);
	if (abs(transpose_read - transpose_pot_old) > JITTER)
	{
		transpose_pot_old = transpose_read;
		if (!switch_transpose_offset)
		{
			if (transpose_read > TO_VOLT)
			{
				transpose_read = transpose_read - TO_VOLT;
				transpose_offset = true;
			}
			else
			{
				transpose_offset = false;
			}
		}
		transpose_pot = Transpose_Mode(transpose_read, transpose_mode);
	}

	//****************************************************************************************************************************
	// ::::::::::::::::::::::::::::::::::::::::::::::::::: Remote Trigger :::::::::::::::::::::::::::::::::::::::::::::::::::::::
	//***************************************************************************************************************************/
	
	// Remote trigger signal ready for processing
	static bool remote_trigger = false; 
	// Only trigger on high to low
	static bool remote_trigger_reset = true;

	if (digitalRead(REMOTE_TRIGGER_PIN) == LOW && switch_remote_trigger)
	{
		if (remote_trigger_reset)
		{
			remote_trigger = true;
			remote_trigger_reset = false;
		}
	}
	else
	{
		remote_trigger_reset = true;
	}

	//****************************************************************************************************************************
	//::::::::::::::::::::::::::::::::::::::::::::::::::::: Transpose CV ::::::::::::::::::::::::::::::::::::::::::::::::::::::::::
	//***************************************************************************************************************************/
	static int transpose_cv = 0;
	static int transpose_cv_old = INVALID_VALUE; 
	transpose_read = analogRead(ANALOG_TRANSPOSE_CV_PIN);
	if (abs(transpose_read - transpose_cv_old) > JITTER || encoder1_move != 0)
	{
		transpose_cv_old = transpose_read;
		transpose_cv = Transpose_Mode(transpose_read, transpose_mode);
	}

	//****************************************************************************************************************************
	//::::::::::::::::::::::::::::::::::::::::::::::::::::::: PITCH CV :::::::::::::::::::::::::::::::::::::::::::::::::::::::
	//***************************************************************************************************************************/
	// dac_chromatic_scale array index to set DAC
	static int ain_tone_index = 0;
	static int pitch_cv_old = INVALID_VALUE;
	int pitch_cv = analogRead(ANALOG_PITCH_CV_PIN) + transpose_cv + transpose_pot;
	if (abs(pitch_cv_old - pitch_cv) > JITTER)
	{
		pitch_cv_old = pitch_cv;
		ain_tone_index = map(pitch_cv, -6, 1017, 0, 84);  // 0-1023 (-6) for shift midt tone, maybe ruined by jitter rejection
		ain_tone_index = Next_Note(scale, ain_tone_index);

		// if end of DAC array find first note down and add root_key index
		if (ain_tone_index + root_key > chromatic_scale_length)
		{
			ain_tone_index = Next_note_down(scale, chromatic_scale_length - root_key) + root_key;
		}
		else
		{
			ain_tone_index = ain_tone_index + root_key;
		}

		// stop at end of array
		if (ain_tone_index > chromatic_scale_length)
		{
			ain_tone_index = chromatic_scale_length; // chromatic_scale_length;
		}
	}
	//****************************************************************************************************************************
	//::::::::::: Set DAC and pulse Gate out if new note or Remote tigger signal:::::::::::::::::::::::::::::::::::::::::::::::::::
	//::::::::::: not all input changes lead to new output notes ::::::::::::::::::::::::::::::::::::::::::::::::::::::::::::::::::
	//****************************************************************************************************************************/
	static int gateLoopCounter = 0;
	if (gateLoopCounter != 0)		// count down gate loop counter and end gate pulse at =1
	{
		if (gateLoopCounter == 1)
		{
			digitalWrite(GATE_PIN, LOW);
		}
		gateLoopCounter--;
	}
	if (ain_tone_index != previous_note)
	{
		if (!switch_remote_trigger || remote_trigger)
		{
			digitalWrite(GATE_PIN, HIGH); 
			gateLoopCounter = GATE_TIME;		// start gate pulse

			if (transpose_offset)
			{
				digitalWrite(TRANSPOSE_OFFSET_PIN, HIGH);
			}
			else
			{
				digitalWrite(TRANSPOSE_OFFSET_PIN, LOW);
			}
			Set_DAC_4921(dac_chromatic_scale[ain_tone_index]);
			previous_note = ain_tone_index;
		}
	}
	else
	{
		if (remote_trigger)		// same note, only pulse gate out
		{
			// pulse gate out with pitch change
			digitalWrite(GATE_PIN, HIGH); 
			gateLoopCounter = GATE_TIME;		// start gate pulse
		}
	}
	remote_trigger = false;
}

// Transpose cv_value according to mode selection
// - returns transposed CV
int Transpose_Mode(int cv_value, int mode) {
	mode = mode % (_MODE_COUNT);
	switch (mode)
	{
	case 0: // //CV transposing in Semitones
	default:
		break;
	case 1: //CV transposing in Fifths (7 Semitones)
		cv_value = map(cv_value, 0, 1023, 0, 12) * 85; // 85 bit = 7 seminotes
		break;
	case 2:	//CV transposing in Octaves (12 Semitones) 
		cv_value = map(cv_value, 0, 1023, 0, 7) * 146; // 146 bit = 12 seminotes
		break;
	}
	return cv_value;
}

bool Encoder1_Move() {
	encoder1_move = 0;
	encoder1_new_position = encoder1.read();
	encoder1_move = (encoder1_new_position - encoder1_counter) / 4;
	if (encoder1_move != 0)
	{
		encoder1_counter = encoder1_new_position;
		return true;
	}
	return false;
}

void Segment_Display(byte value) {
	for (int i = 0; i < 8; i++)
	{
		digitalWrite(segment_array[i], bitRead(value, i));
	}
}

// subroutine to set DAC on MCP4921
void Set_DAC_4921(int DC_Value) {
	lower_byte = DC_Value & 0xff;
	upper_byte = (DC_Value >> 8) & 0x0f;
	bitSet(upper_byte, 4);
	bitSet(upper_byte, 5);
	digitalWrite(DAC_CS_PIN, LOW);
	tfr_byte(upper_byte);
	tfr_byte(lower_byte);
	digitalWrite(DAC_SDI_PIN, LOW);
	digitalWrite(DAC_CS_PIN, HIGH);
	digitalWrite(DAC_LDAC_PIN, LOW);
	digitalWrite(DAC_LDAC_PIN, HIGH);
}

// transfers a byte, a bit at a time, LSB first to the DAC
void tfr_byte(byte data) {
	for (int i = 0; i < 8; i++, data <<= 1) {
		digitalWrite(DAC_SDI_PIN, data & 0x80);
		pulseHigh(DAC_SCK_PIN);   //after each bit sent, CLK is pulsed high
	}
}

void DACsetup() {
	pinMode(DAC_CS_PIN, OUTPUT);
	pinMode(DAC_SCK_PIN, OUTPUT);
	pinMode(DAC_SDI_PIN, OUTPUT);
	pinMode(DAC_LDAC_PIN, OUTPUT);

	digitalWrite(DAC_CS_PIN, HIGH);
	digitalWrite(DAC_LDAC_PIN, HIGH);
	digitalWrite(DAC_SCK_PIN, LOW);
	digitalWrite(DAC_SDI_PIN, HIGH);

	Set_DAC_4921(0);
}

int Next_Note(int selected_scale, int index) {
	int up = Next_note_up(selected_scale, index);
	int down = Next_note_down(selected_scale, index);

	if (up - index < index - down)
	{
		down = up;
	}
	return down;
}

int Next_note_up(int selected_scale, int index) {
	while (!scale_array[selected_scale][index % 12])
	{
		index++;
	}
	if (index > chromatic_scale_length)
	{
		index = index + 12; // if out of range, exclude next_note_up from being closest note
	}
	return index;
}

int Next_note_down(int selected_scale, int index) {
	while (!scale_array[selected_scale][index % 12])
	{
		index--;
		if (index < 0)
		{
			index = 0;
			index = Next_note_up(selected_scale, index);
		}
	}
	return index;
}
